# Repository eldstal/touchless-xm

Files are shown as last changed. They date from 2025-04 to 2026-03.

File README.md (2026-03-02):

# Touchlæss XM

A mod for Sony WH-1000XM2 (experimental), WH-1000XM3, WH-1000XM4 and WH-1000XM5 (experimental) headphones to remove the gesture-based touch controls and add physical buttons.

- [Project Status](#Status)
- [Compatible headsets](#compatibility)
- [Modifications](#modifications-and-faq)
- [How to program your board](#how-to-program)
- [Notes on ordering PCBs](#fabrication-notes)
- [License](#license)

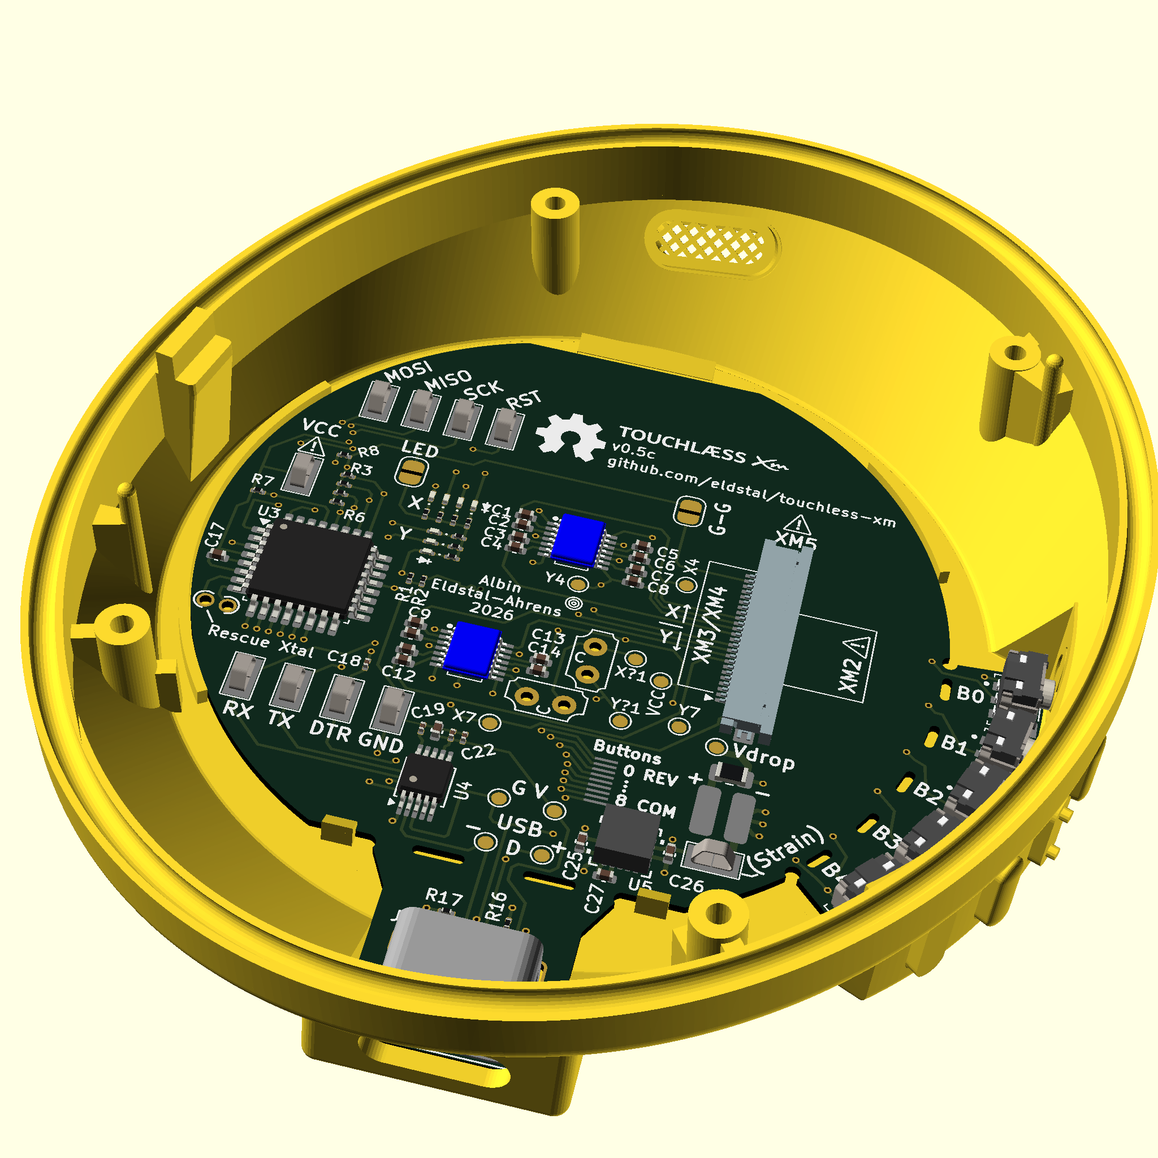
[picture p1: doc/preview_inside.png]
Inside view
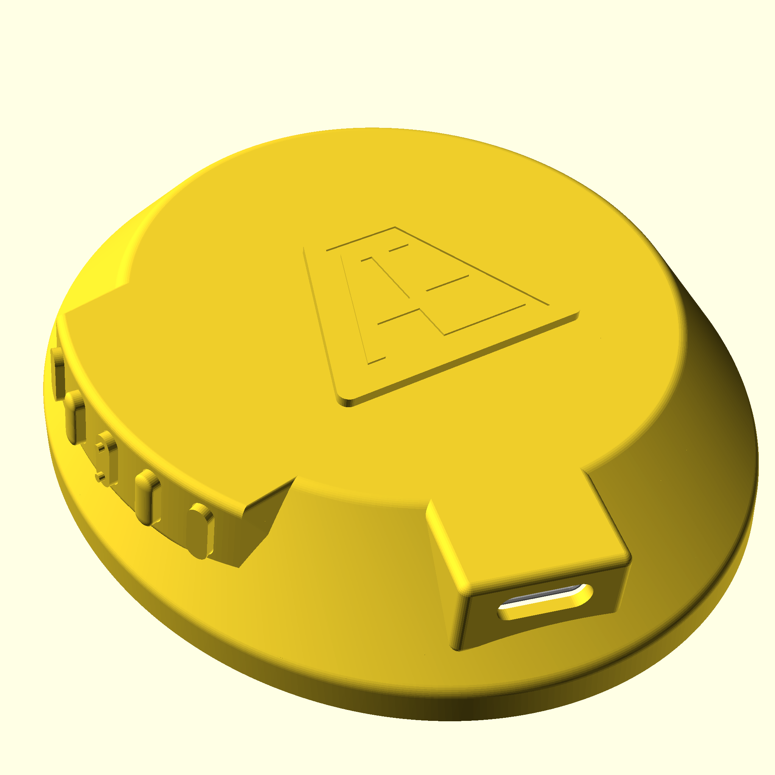
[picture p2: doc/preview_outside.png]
Outside view
 

## Status
The project is feature-complete and the electronics are functional. I'd call it a Beta product, since I'm the only user and still tweaking the design details.

### Case
The design has been 3D-printed and test fit against an XM4 headset. The mic grill looks good but prints awful.
Could be that we need to use a metal mesh inserted during the print.

The buttons have different top surfaces, so you can feel which is which. They've also been relocated to be less likely to be accidentally actuated.

STLs will be available both with and without USB ports, with and without the Æ logo.

### PCB
v0.5c of the board has been manufactured and works great!

I've installed it in my own headset for some day-to-day testing.

### Firmware
Ready to go. USB support (only for programming) is already included in the main board. The project uses platform.io and OptiBoot to run an Arduino-based firmware.

## Compatibility
I only have a pair of XM4 to test with, so the design is made to fit them. The connector is a 24-pin, but only XM5 has a cable that wide. For other models, insert your narrower cable carefully to match the lines on the PCB.

### 🟡 Sony WH-1000XM2 (Experimental)
I've laid out the board for experimental support for the XM2. These are the most different out of the bunch, so there are caveats.

⚠️**WARNING**⚠️
The OEM cable will not work, because the XM2 has the touch board's connector at the front. You will need a slightly longer cable **with opposite side contacts**. Possibly [This Würth 687712100002](https://eu.mouser.com/ProductDetail/Wurth-Elektronik/687712100002?qs=PhR8RmCirEbjmYLiy2w9eg%3D%3D) is suitable, but too long of a cable will cause interference. If you can trim it to length, that will improve the chances of success.

There is no bespoke connector for the XM2, you need to very carefully position it in the larger connector using the lines on the PCB.

It's also necessary to modify the firmware pin map slightly, since the Y pins are in the opposite order. Use `--environment xm2` when you compile the firmware.

If you've got a pair of XM2s and want to help me tune the compatibility, let me know!

### 🟡 Sony WH-1000XM3 (Probably compatible)
The XM3 touch board and battery connector appear to be electrically identical to XM4, so the PCB should be compatible. A different case design may be needed.

Insert your cable all the way at the top of the connector (there will be two unused pins at the bottom). Follow the lines in the silkscreen for guidance.

### 🟢 Sony WH-1000XM4 (Compatible)
The project is designed for these, so these will be the ones primarily tested. The OEM touch board has a flat cable which Touchlæss is designed to reuse.

Insert your cable all the way at the top of the connector (there will be two unused pins at the bottom). Follow the lines in the silkscreen for guidance.

The battery uses a 2-pin JST ZH series connector. There is no vertical space inside the case for a matching connector on the board, so I've resorted to soldering a Y-connector onto the Touchlæss pcb. Separate from the PCB BOM, you'll need one male and one female JST ZH-2 connector and some red/black cables.

### 🟡 Sony WH-1000XM5 (Possibly compatible)
Experimental support is included in the initial board design, but I **do not** own a pair of XM5 and cannot test them. The XM5 pinout is entirely based on reverse-engineering of photos, so I may have made a mistake! The Touchless board shouldn't be able to do any damage to the headphones. If you have a pair of XM5s and would like to help me test the compatibility, feel free to reach out!

At a minimum, the XM5 OEM design doesn't include a loose cable for us to reuse. You will need a suitable flat cable, which is 24-pin FFC with 0.5mm pitch and same-side connectors. [This Würth 687624050002](https://eu.mouser.com/ProductDetail/Wurth-Elektronik/687624050002?qs=P%2FTEqz%252BQfndQFFKLalvVUA%3D%3D) should work, but may not be the proper length.

The battery connector for XM5 is also different, a 3-pin of unknown design. If you have more information about this, let me know!

### 🟡 Sony WH-1000XM6 (Not even released yet)
With any luck, the XM6 touch board will be similar to the XM5. It will be a while before I get my hands on a new high-end headset to test it, though.

If you're getting a pair of XM6 and would like to send me some nice photos of the internals, I'll be very grateful!

### 🔴 Other manufacturers/headsets
**Highly** unlikely. At the very least, you'll need to figure out the pinout for the touch sensor board. Most likely there will be other things that need tuning as well. If you want to make something like touchless for a different headset, take a look at the [technical documentation](doc/README.md) for some pointers on how Touchless works.

## Modifications and FAQ

#### Will it drain my battery?
Not really. When idle, the board draws about 0.02 mA. When you're actively pressing/holding buttons it peaks at just under 13mA. This is on the order of one LED, and only when you're actively pushing buttons.

The DC converter on the board will stop working once the battery drops below about 0.7V, which is quite a bit before the headphones actually stop working. That means the buttons won't work when your battery is very low.

#### I don't want another USB port on my headset
That's OK, it's only needed for development (reprogramming the Touchless board without disassembling the headphones). Simply snap the USB connector off from the main board (see perforations) and print yourself a case without a USB block. Set `cap_type=nousb` in `xm4-cap.scad` to get a case that's closed at the bottom.

#### I don't like how you've placed the buttons
That's no problem! Snap the button portion off of the main board (see perforations) and use the solder points on the front or back to connect your own buttons placed wherever you want them. If you're keen on PCB design, it's not that hard to redesign the PCB for button placement (or add/remove buttons as needed).

There is no need for external resistors etc, just connect a switch between one button contact and the COM and you're good to go.

#### I don't have a 3D printer
No problem! If you remove the buttons and the USB addition (see above), the touchless board should fit inside the OEM ear cup (you have to remove the original touch board first, which may be destructive). Make cuts in the case as needed to mount buttons where you want them, and wire them up to the exposed button solder points on the front or back of the PCB.

#### The case is fine, but I want to reconfigure the buttons
Easiest way to do this is in the firmware. Take a look at [buttonmap.cpp](firmware/tobo/src/buttonmap.cpp) to switch and swap however you like. You'll need the included USB port or a serial cable to program the board after you've made your modifications. Instructions are [down below](#step-2-firmware).

#### Any tips for software modifications?
The board itself works as its own development board, of sorts. If you're going to be flashing new software via USB while testing, I recommend connecting the USB V (+5v) pad to the VCC test point as shown in [this photo](doc/usbpower.png). If you also short out the "LED" solder bridge you get LED indications of which touch points are currently being "touched".

**Please disconnect the USB power jumper before installing in the headset and connecting a battery**

#### I want to design my own case
Great! You can find the dimensions of the PCB [here](doc/tobo-measurements.svg). It's all  relative to the center of the circular area, so if your CAD program supports polar coordinates you'll have an easier time of it. You may also have use for `make vrml` in the pcb directory, which creates a VRML 3D export of the PCB to use as a reference in your model.

#### I want buttons for other features
That won't be possible, sorry. Touchlæss only works by simulating touches and swipes, so it can only do what the headphones allow you to do with the touch panel.

#### The buttons are too slow!
Yes. There is a significant delay between pushing a button and the headset responding. This isn't something we can control, since Touchlæss simulates touch gestures. If a swipe takes 120ms to perform, the headset can't react sooner than that.

#### I want the buttons on the left cup
That will be an adventure. Touchlæss interfaces with the board in the right cup, so you'll need to run wires across the headband to get to the other side. Not impossible, but certainly a lot of work.

#### I want to make and sell these
That's great! I won't ask for any royalties or whatever. If you do set something up, I'm happy to include a link here so people can buy from you.

## How to program

**Note:** The VCC loop on the PCB is powered by the headset battery via a step up/step down converter configured for 3.3V. **Do not** connect an external supply to this hook while the battery is connected. The loop is only needed in order to program and test the board without a headset connected.

The board will not take power from the USB connector by default. If you want to power it via USB while programming, connect a jumper between the USB V test point and the VCC test point as illustrated [here](doc/usbpower.png). Disconnect that jumper again before connecting a battery, please.

### Step 1: Bootloader
**This only needs to be done once per board**

When you have a fresh board with a factory-stock microcontroller, you'll have to start with the bootloader. For this step you need a hardware AVR programmer, for example:

- AVRISPmk2 (tested, works)
- An Arduino ([Instructions](https://docs.arduino.cc/built-in-examples/arduino-isp/ArduinoISP/#how-to-wire-your-boards))
- A [Bus Pirate](http://www.dangerousprototypes.com/docs/Bus_Pirate_AVR_Programming)
- An [USBAsp](https://www.fischl.de/usbasp/)

...or anything else supported by avrdude or [platform.io](https://platformio.org/). Install [the platform.io tools](https://platformio.org/install/cli) and let's go!

1. Connect your programmer to MISO, MOSI, SCK, GND and RST.
2. Connect the battery or the VCC terminal

| tobo | AVRISP 10-pin |Glasgow | BP harness |
|---|---|---|---|
| MOSI | 1 | PURP | 8 Pink |
| VCC  | 2 | ORG | 2 White |
| RST  | 5 | YEL | 6 Green |
| SCK  | 7 | PINK | 7 Yellow |
| MISO | 9 | BRN | 10 Brown |
| GND  | 10 | B/W | 1 Black |

If you're using a new kind of programmer, add the needed environment to `firmware/tobo/platformio.ini` to use your programmer.

**Warning** Ensure that your new environment extends `env:tobo`, so that the frequency and fuses are programmed properly. If you do not, you may need to temporarily connect an external crystal (see PCB markings) in order to recover the board.

```
cd firmware/tobo
pio run --environment avrispv2 --target bootloader
```

If there are no errors, congratulations! Your tobo board is an Arduino! You're ready for the next step.

### Step 2: Firmware
**If you've made changes to the code and want to update your board, this step is the only one you need to repeat**

If your board has the bootloader installed, you can put your ISP programmer away and use either the on-board USB port or your own serial adapter. This can be an FTDI cable, a different USB-to-serial adapter, or an arduino board with no microcontroller.

Hook up your serial cable to the tobo:

| tobo | serial adapter |
|---|---|
| RX | TX |
| TX | RX |
| GND | GND |
| DTR | DTR (if your cable has it) |
| RST | RST (if using an arduino) |
| VCC  | VCC **Only if you don't have the battery plugged in**|

```
cd firmware/tobo
pio run --target upload
```

If all went well, you're ready to go!

## Fabrication Notes
I've had the board produced by PCBWay with no issues. The following facts are useful while setting up an order:

- Order a 0.6mm PCB, to maximize the clearance inside the cap
- The smallest drilled hole is just over 0.2mm
- The XM4/XM5 connector footprints have narrow spacing between pads. This is a problem for the "Matte black" solder mask, but apparently possible with green/blue/red solder mask. If you want a matte black board, you have to allow for gaps in the solder mask at these connectors, and that may lead to shorts. Go with green or blue or red.

## Cost
The total cost for production, components and assembly of 5 boards was about $280 including shipping to Europe and VAT. That works out to about $56 per board.
You can reduce the BOM cost some by removing the USB port, USB-Serial circuitry and the LEDs. You could also save a bit by not populating the test loops, but it will make it more difficult to program the board.

## License
Touchlæss XM © 2026 by Albin Eldstål-Ahrens is licensed under Creative Commons BY-SA 4.0 

This means you are free to use, modify, distribute, remix, redesign the project however you wish as long as you
1. Credit the original work where relevant
2. Release your own modified work under a similar CC license

If you want to make and sell kits of this, feel free! If you make money from my work, please consider making a donation to a charitable organization as a thank you!

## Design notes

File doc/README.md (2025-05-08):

# Technical docs

## How does it work?

All three XM* headsets use the same basic principle for their touch controls, a grid of pads arranged in rows (Y) and columns (X). A pair of one X and one Y pad make up a single cell of a [mutual capacitive touch](https://www.elektormagazine.com/articles/how-do-capacitive-touch-sensors-work) matrix.

The controller board in the headphones uses various analog tricks to measure the capacitance of each X/Y pair, one at a time. When a finger is near, the capacitance between the pads **drops**.

### How does Touchless simulate this?

The easy and "safe" way to replace the touch board is to simulate the drop in capacitance, rather than trying to emulate the resulting analog signal. Touchless does this by connecting two capacitors between an X pad and a Y pad, and having one of the two capacitors connected via a multiplexer. This allows us to cut the capacitance in half by breaking the circuit, simulating a touch event.

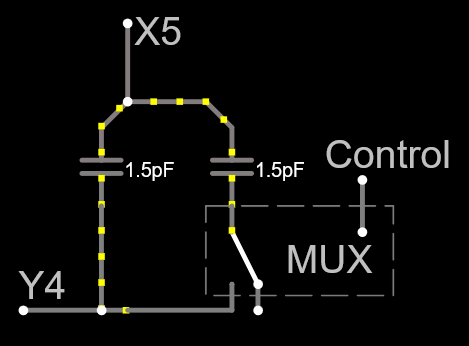
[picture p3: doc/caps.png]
Two capacitors, one controlled by a Mux


To support swiping motions, Touchless attaches to four horizontal and four vertical points in the touch matrix. This lets us control touch events at the following coordinates: 

```
-     -     -     -     -     -
-     -     -     -     -     -
-     -   (2,7)   -     -     -
-     -   (2,6)   -     -     -
-     -   (2,5)   -     -     -
-   (1,4) (2,4) (3,4) (4,4)   -
-     -     -     -     -     - 
-     -     -     -     -     -
```

Prototype testing indicates that three points are enough for a working swipe on the XM4, so this should be sufficient for all gestures.

## Original hardware
### WH1000-XM2

#### Battery connector
Battery appears to be a cellphone-type with no cables attached to it. It sits in a cradle which *does* have a cable+connector to the board, though.

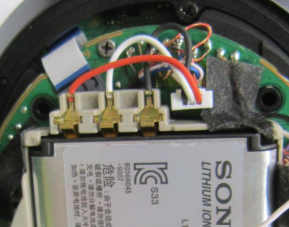
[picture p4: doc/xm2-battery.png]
XM2 battery from FCC filing


It's a 3-pin, likely JST but does not match the XM4 or XM5.

#### Touch board connector
FCC filing contains an OK shot of the touch board. The connector is at the front!

Pin 12 toward the top of the PCB/cap

| Pin  | Name |
|---|---|
|  12  |  ? |
|  11  |  X4  |
|  10  |  X3  |
| 9  |  X2  |
| 8  |  X1  |
| 7  |  X0  |
| 6  |  NC  |
| 5  |  Y3  |
| 4  |  Y2  |
| 3  |  Y1  |
| 2  |  Y0  |
| 1  |  ? |

Because the headphones have their connector at the front and tobo has its connector at the rear, you'll need a cable with **opposite side** connectors (i.e. exposed connectors on the front on one end and on the back on the other end). The cable also needs to be a bit longer than the OEM one.

### WH1000-XM3

Connectors (based on photos) appear to be identical to WH1000-XM4.

### WH1000-XM4

#### Battery connector
This is a 2-pin [JST ZH-series connector](https://www.jst-mfg.com/product/pdf/eng/eZH.pdf). The matching board connector is too tall to fit on the Touchless board, so the current design has no connector. Solder bare wires to the pcb and run them through a test loop for strain relief.

#### Touch board connector

FFC-22 with a 0.5mm pitch. With pin 22 at the top of the touch board, this is the pinout:

| Pin  | Name |
|---|---|
|  22  |  Some sort of ground loop around the edge |
|  21  |  GND |
|  20  |  NC  |
|  19  |  Unknown  |
|  18  |  X6  |
|  17  |  X5  |
|  16  |  X7  |
|  15  |  X8  |
|  14  |  X4  |
|  13  |  X3  |
|  12  |  X2  |
|  11  |  X1  |
|  10  |  X0  |
|  9 |  Y4  |
|  8 |  Y5  |
|  7 |  Y6  |
|  6 |  Y7  |
|  5 |  Y8  |
|  4 |  Y3  |
|  3 |  Y0  |
|  2 |  Y1  |
|  1 |  Y2  |

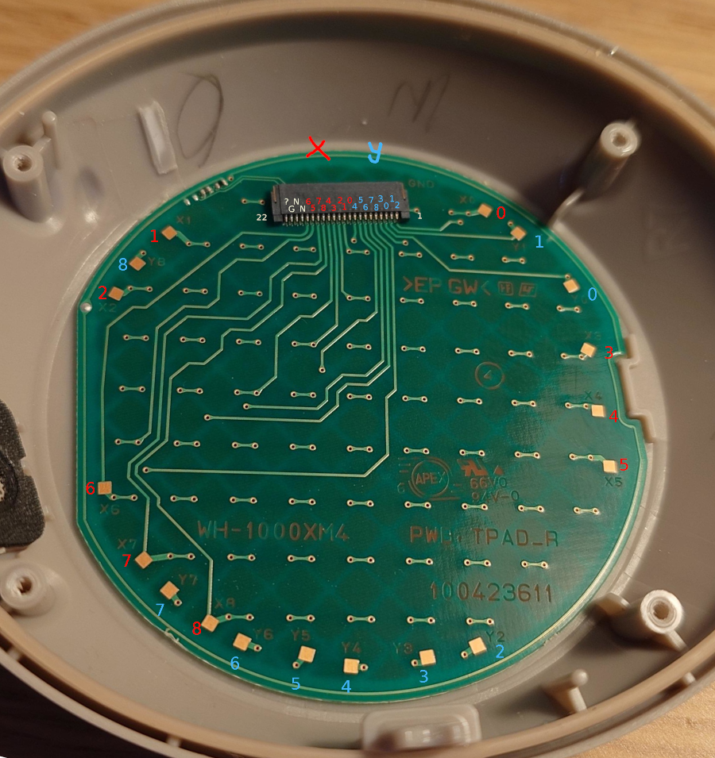
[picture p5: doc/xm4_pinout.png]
XM4 touch board with annotations


A compatible-ish part with a low profile is [Molex 545482272](https://www.molex.com/en-us/products/part-detail-pdf/545482272?display=pdf)

### WH1000-XM5

**This info is based on photos found online** and not from actual measurements on the real headset. Don't trust these numbers.

#### Battery connector
3-pin of unknown model. For sure not compatible with the XM4.

Inserted part seems to be ~7.3mm wide and inserted to 4mm depth.
The outer terminals are about 4mm apart, and there's a single smaller pin for the temp sensor.

It's labeled JST, and the closest I've been able to find is the [LBT-A](https://www.jst.com/products/crimp-style-connectors-wire-to-board-type/lbt-connector-a-type/), probably model `LBTAR-03V-2K-K(HF)`

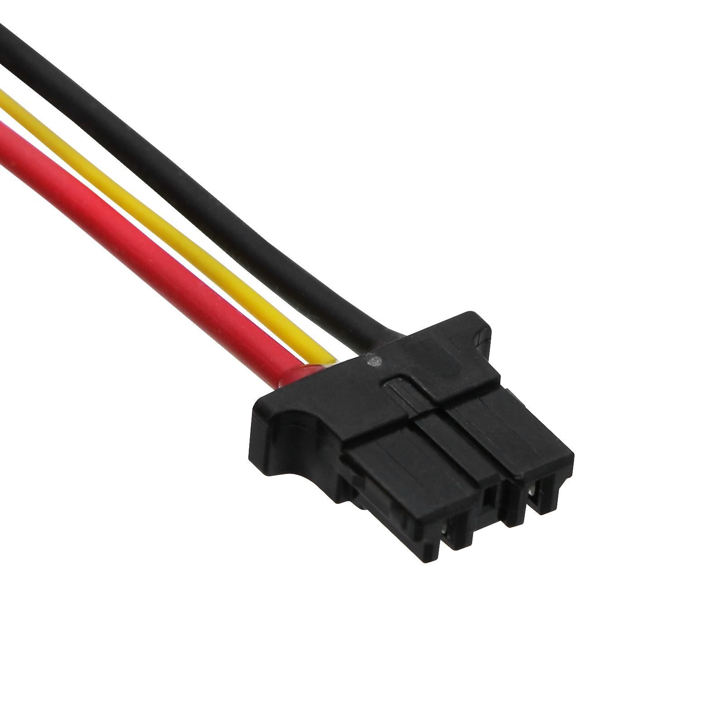
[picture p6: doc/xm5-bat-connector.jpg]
XM5 battery connector closeup


#### Touch board connector
24-pin 0.5mm pitch FPC integrated in the touch board (no connector on that end).

Touch panel is an FPC and has no connector of its own, the cable is combined with the circuit board itself. This pinout is for an imaginary connector, if you were to replace the FPC with a PCB and use a straight 24-pin FFC cable from the motherboard to the touch panel.

A suitable connector might be [Molex 545482472](https://www.molex.com/en-us/products/part-detail-pdf/545482472?display=pdf).

Pin 24 is at the top, 1 is at the bottom.

| Pin  | Name |
|---|---|
|  24  | Some kind of ground loop around the board  |
|  23  | GND  |
|  22  | NC |
|  21  | X0 |
|  20  | X6 |
|  19  | X5 |
|  18  | X7 |
|  17  | X8 |
|  16  | X4 |
|  15  | X3 |
|  14  | X2?  |
|  13  | X1?  |
|  12  | NC |
|  11  | Y4 |
|  10  | Y5 |
|  9 | Y6 |
|  8 | Y7 |
|  7 | Y8 |
|  6 | Y3 |
|  5 | Y9 |
|  4 | Y10  |
|  3 | Y2 |
|  2 | Y1 |
|  1 | Y0 |

The current PCB design for Touchless has an XM5 connector, which is based on this presumed pinout. If you have an XM5 headset and can provide a pinout, please let me know!

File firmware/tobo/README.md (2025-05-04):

# Touchless Board (tobo) firmware

## First time installation (bootloader)
Connect an ISP programmer (e.g. an AVRISPmk2 or an arduino wired up to MOSI/MISO/SCK/RST) and run

```
pio run --env avrispv2 --target bootloader --upload-port=/dev/ttyUSB0
```

## Update firmware
Connect to the RX/TX/RST hooks (or via the on-board USB connector) and run
```
pio run --target upload --upload-port=/dev/ttyUSB0
```

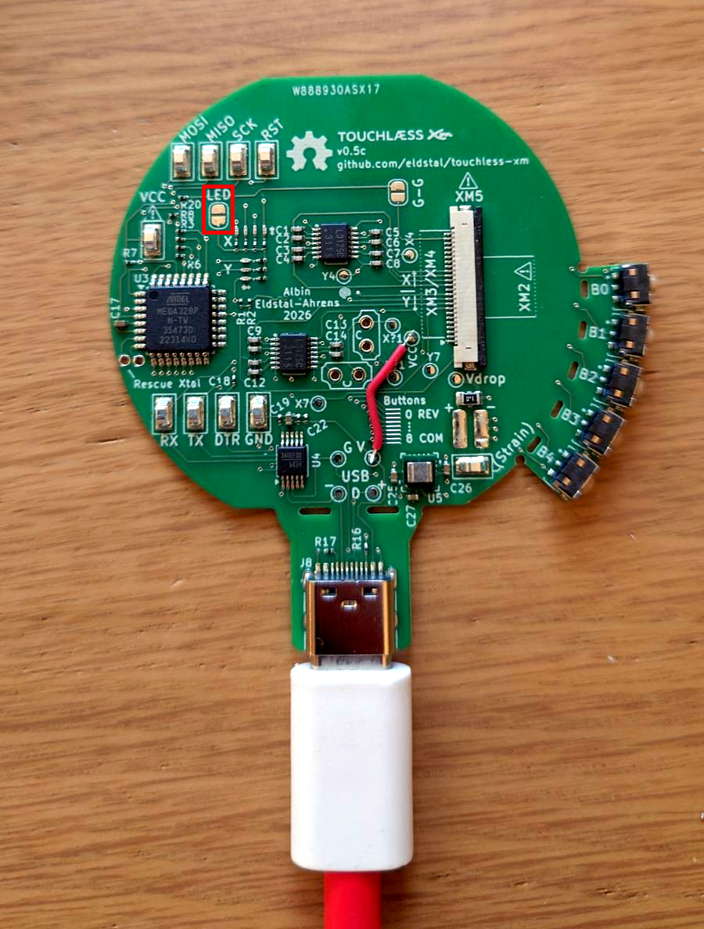
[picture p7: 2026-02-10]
doc/usbpower.png

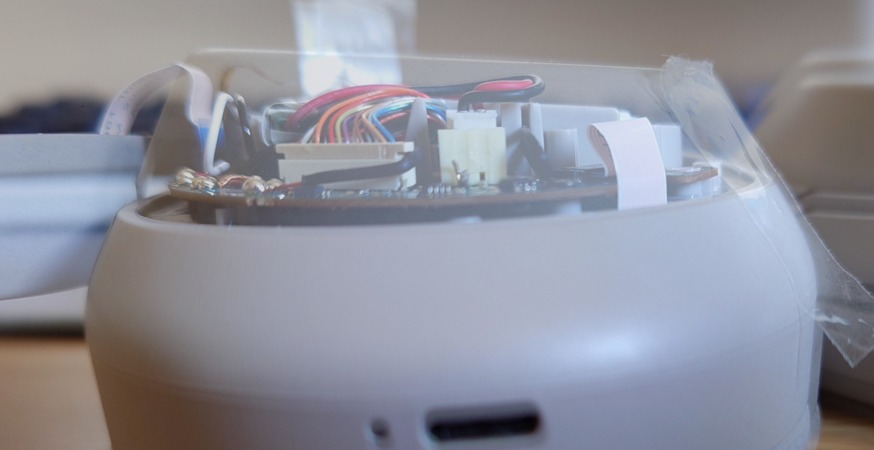
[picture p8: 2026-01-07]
doc/xm4-ghost.png

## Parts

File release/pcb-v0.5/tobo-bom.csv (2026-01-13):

Designator | Quantity per PCB | Manufacturer_Part_Number | Value | Mouser Part Number | LCSC Part Number | Datasheet | Footprint
C1-C14 | 14 | CC0402BRNPO9BN1R5 | 1.5pF |  | C282238 | ~ | Capacitor_SMD:C_0402_1005Metric
C17,C20,C25 | 3 | CL05A106MP5NUNC | 10uF |  | C315248 | ~ | Capacitor_SMD:C_0402_1005Metric
C18,C19,C21,C22 | 4 | TMK063ABJ104KP-F | 0.1uF | 963-TMK063ABJ104KP-F |  | ~ | Capacitor_SMD:C_0201_0603Metric
C26 | 1 | CL05A226MQ5QUNC | 22uF |  | C105226 | ~ | Capacitor_SMD:C_0402_1005Metric
C27 | 1 | CL05A225KO5NQNC | 2.2uF |  | C170151 | ~ | Capacitor_SMD:C_0402_1005Metric
D1-D7 | 7 | XL-0201UYC | LED |  | C5440628 | ~ | LED_SMD:LED_0201_0603Metric
J4 | 1 | 538-54548-2472 | 54548-2472 | 538-54548-2472 |  | https://www.molex.com/en-us/products/part-detail-pdf/545482472?display=pdf | tobo-footprints:molex-545482472
J8 | 1 | TYPE-C-31-M-12 | Hroparts Elec TYPE-C-31-M-12 |  | C165948 | https://www.usb.org/sites/default/files/documents/usb_type-c.zip | Connector_USB:USB_C_Receptacle_HRO_TYPE-C-31-M-12
R1-R8,R20 | 9 | ERJ-1GJJ102C | 1K | 667-ERJ-1GJJ102C |  | ~ | Resistor_SMD:R_0201_0603Metric
R9-R15 | 7 | ERJ-1GNF2700C | 270 | 667-ERJ-1GNF2700C |  | ~ | Resistor_SMD:R_0201_0603Metric
R16,R17 | 2 | ERA-1AEC512C | 5.1K | 667-ERA-1AEC512C |  | ~ | Resistor_SMD:R_0201_0603Metric
R27 | 1 | ERJ-6DQF1R0V | 1 | 667-ERJ-6DQF1R0V |  | ~ | Resistor_SMD:R_0805_2012Metric
S1-S5 | 5 | SKRTLBE010 | SKRTLBE010 | 688-SKRTLB |  | https://tech.alpsalpine.com/e/products/detail/SKRTLBE010/ | tobo-footprints:SKRTLBE010
U1,U2 | 2 | TC7MBL3125CFK(EL) | ~ | 757-TC7MBL3125CFKEL |  |  | tobo-footprints:VSSOP50P400X100-14N
U3 | 1 | ATmega328P-AN | ATmega328P-AN | 556-ATMEGA328P-AN | C618732 | http://ww1.microchip.com/downloads/en/DeviceDoc/ATmega328_P%20AVR%20MCU%20with%20picoPower%20Technology%20Data%20Sheet%2040001984A.pdf | Package_QFP:TQFP-32_7x7mm_P0.8mm
U4 | 1 | CH340E | CH340E |  | C99652 | https://www.mpja.com/download/35227cpdata.pdf | tobo-footprints:MSOP-10_3x3mm_P0.5mm_narrowpads
U5 | 1 | MAXM20343AMP+ | MAXM20343AMP+ | 700-MAXM20343AMP+ |  | MAXM20343AMP+ | tobo-footprints:21-100447_ADI
U6-U13,U15,U16 | 10 | 5015 | 5015 | 534-5015 |  | http://www.keyelco.com/product-pdf.cfm?p=1353 | tobo-footprints:5015

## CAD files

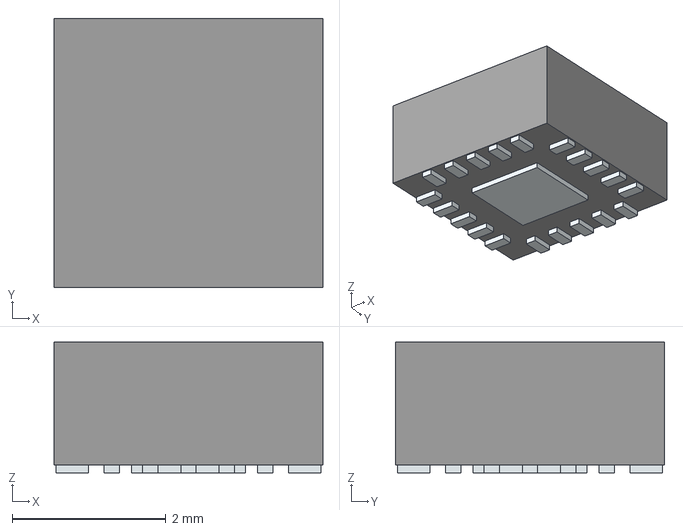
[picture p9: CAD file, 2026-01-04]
pcb/tobo/3dmodels/MAXM20343AMP+.stp
3.50 x 3.50 x 1.70 mm
Pins

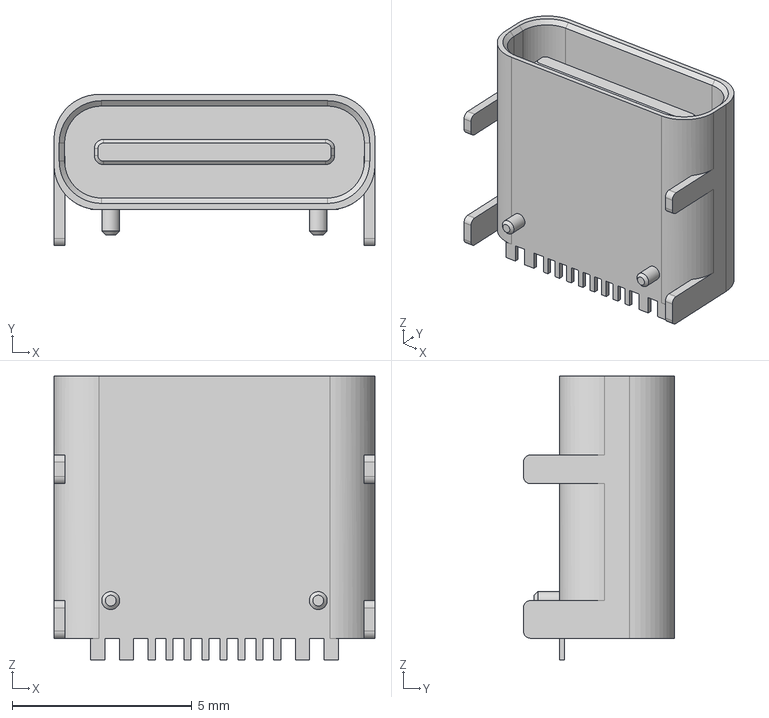
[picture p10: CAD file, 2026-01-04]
pcb/tobo/3dmodels/HRO TYPE-C-31-M-12.step
8.94 x 4.21 x 7.90 mm

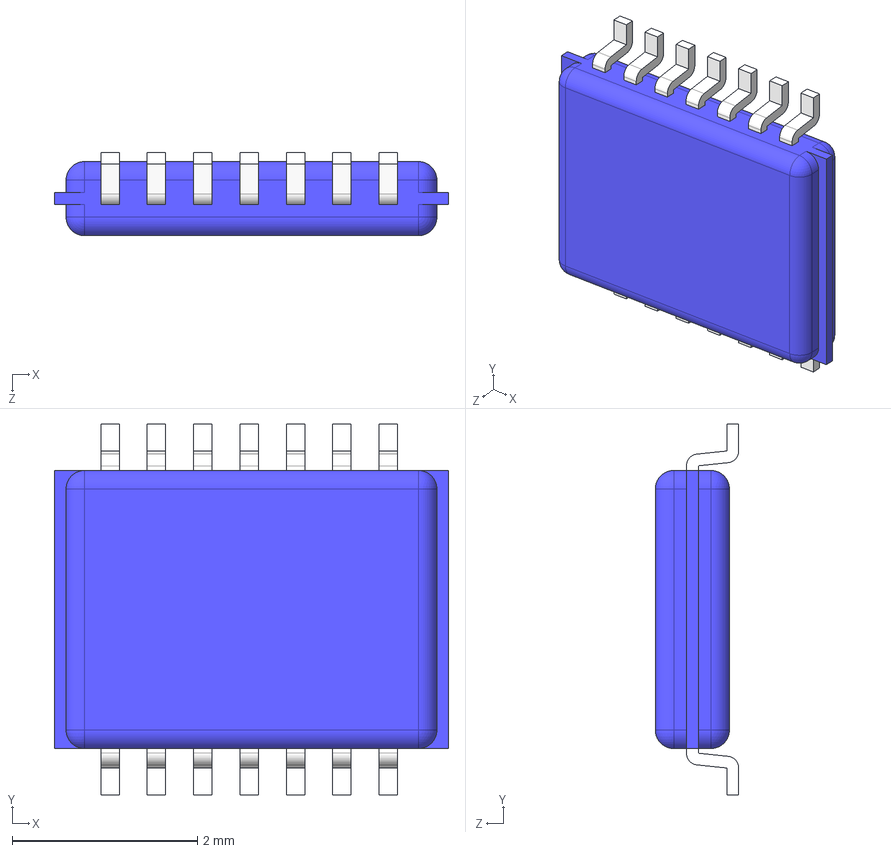
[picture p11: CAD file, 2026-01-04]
pcb/tobo/3dmodels/TC7MBL3125CFK_EL_.stp
4.25 x 4.00 x 0.9 mm

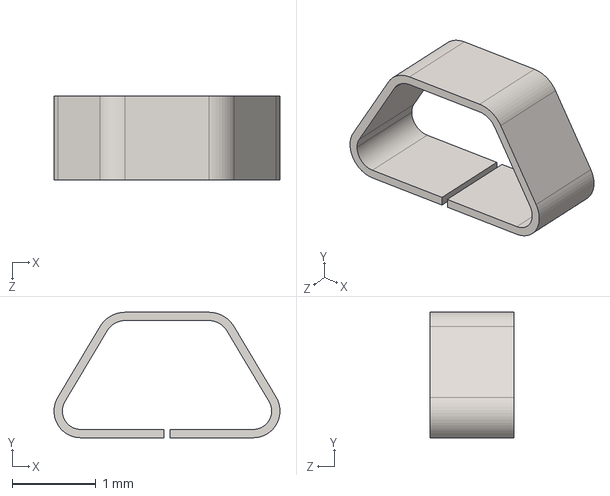
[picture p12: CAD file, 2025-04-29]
pcb/tobo/3dmodels/5015.stp
2.70 x 1.50 x 1.00 mm

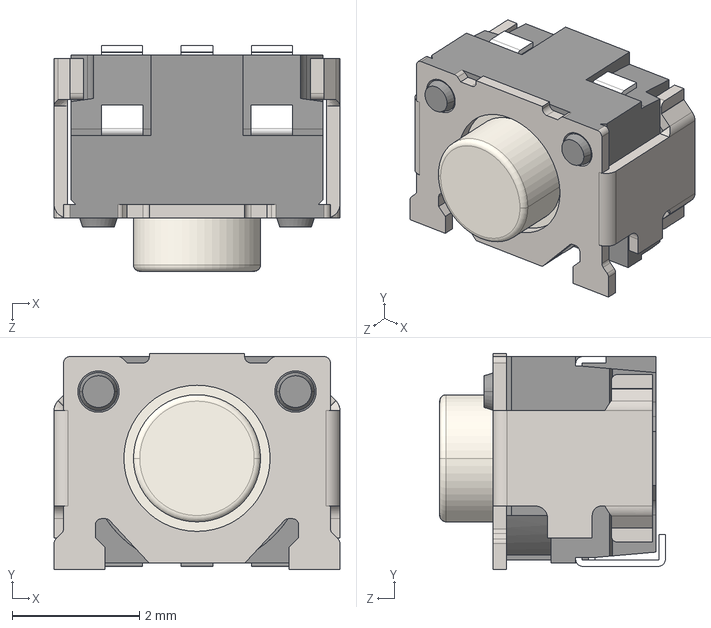
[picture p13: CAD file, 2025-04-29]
pcb/tobo/3dmodels/SKRTLBE010.stp
4.50 x 3.40 x 3.55 mm

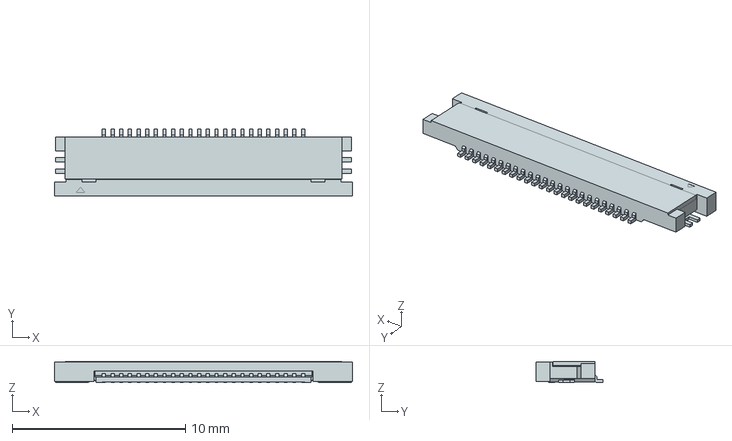
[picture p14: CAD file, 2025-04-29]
pcb/tobo/3dmodels/545482472.stp
17.2 x 3.85 x 1.23 mm

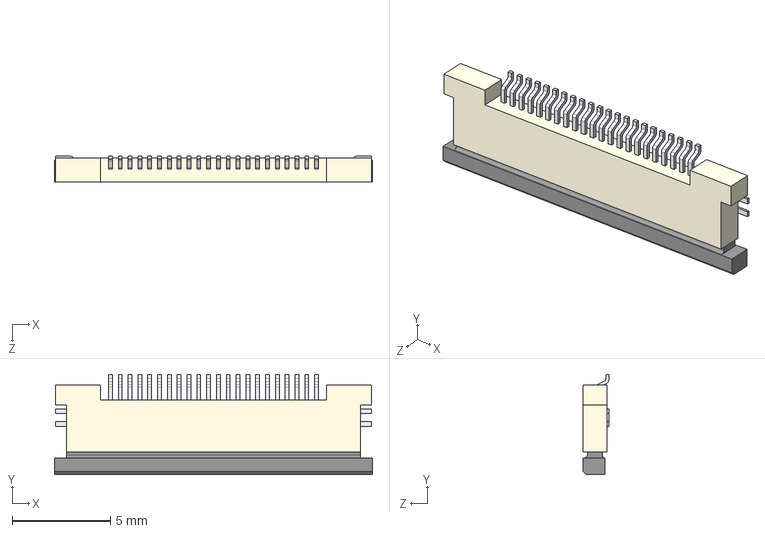
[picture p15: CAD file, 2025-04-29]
pcb/tobo/3dmodels/54548-2272.stp
16.2 x 5.10 x 1.30 mm

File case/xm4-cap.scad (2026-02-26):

//
// Right outside cup for WH1000-XM4
//

/* [Quality etc] */
$fa = 1;
$fs = 0.2;


include_print_supports = true;

/* [Parts included] */
// Render the main body
show_cap = true;

// Render PCB (run make in pcb/)
show_pcb = true;

// Render buttons
show_buttons = true;

// Render microphone grill
show_grill = true;

// Render the logo on the cap
show_logo = true;

/* [Body options] */
cap_type = "usb";        // [usb, nousb, oem]

// Partial rendering
cap_portion = "full";       // [full, mount, cutaway, clearance, buttons, button-cutaway, grill]

body_thickness = 1.4;

gasket_thickness=1.75;

// Width of the flat rim around the bottom
rim_width = 2.6;

/* [Logo options] */
logo_mounted = false;

// Include the mount for the logo amulet on the outside of the cap
with_logo = true;




/* [PCB options] */
// Replace the fancy render with a placeholder for test fits
pcb_type_dummy = false;
pcb_thickness = 0.6;
pcb_clearance = 0.1;
usb_board_h = 4.5;



/* [Button options] */
buttons_mounted = false;

// Distance from PCB center to switch contact surface
button_contact_r = 32.25;

// mm between the button and the button hole
button_side_clearance = 0.1;

// mm between the button and the body
button_depth_clearance=0.15;


/* [Mic grill options] */
grill_mounted = false;

// Oversize the mic grill to make it stick
mic_grill_friction_fit = 0.05;

// Mic hole frame protrusion to meet the mic
mic_grill_protrude_inside = 0.8;

mic_hole_height = 2.5;
mic_hole_width = 8;

/* [Hidden] */
outside_width = 69;
outside_height = 80;
outside_max_depth = 17.1;
top_circle_diameter = 57.5;
top_circle_angle_x = 1.9;
top_circle_angle_y = 5;
top_circle_off_x = 2;       // More like 1 for the OEM, but we needed more button space
top_circle_off_y = 1;
top_circle_off_z_c = 14.5;
inside_depth_c = top_circle_off_z_c - body_thickness;



// The centers of the round radii of the mic hole

mic_hole_x1 = 6.27;
mic_hole_y1 = 39.39;

mic_hole_x2 = 11.96;
mic_hole_y2 = 37.49;

//mic_hole_xc = (mic_hole_x1 + mic_hole_x2) / 2;
mic_hole_xc = 17.34 - 8.5;
mic_hole_yc = (mic_hole_y1 + mic_hole_y2) / 2;
mic_hole_zc = 8;

// Actual opening

// The hole in the case
mic_hole_cut_height = 4;

// Actual opening
mic_hole_cc = mic_hole_width - mic_hole_height;


// Set mic_hole_feeler and tweak until the red panel just breaks the outside edge of the casing
mic_hole_feeler = false;
mic_hole_angle_x = 31.8;
mic_hole_angle_z = 1;
mic_hole_angle_y = -5;
mic_hole_distance = 36.4;
mic_grill_alignment = -1.2;
//mic_hole_angle_z = atan((mic_hole_y2 - mic_hole_y1) / (mic_hole_x2 - mic_hole_x1));


// Heading to the mic hole from the origin
mic_hole_dir_z = -atan((mic_hole_xc) / (mic_hole_yc));
mic_hole_dir_x = asin(mic_hole_zc / mic_hole_distance);


module bottom_outer_edge() {
    import("xm4-cap-outline-centered.svg", center=true);
}

module edge_with_rounding(radius=1.75) {
    
    difference() {
        minkowski() {
            resize([outside_width - 2*radius, outside_height - 2*radius, 0], true)
            linear_extrude(0.01, center=true)
                import("xm4-cap-outline-centered.svg", center=true);
            
            
            sphere(r=radius);
        }
        
        translate([0, 0, -radius])
        scale([outside_width*2, outside_height*2, radius*2])
        cube(center=true);
    }
}


module bottom_gasket(thickness=gasket_thickness,
                     center_width=outside_width - (rim_width),
                     center_height=outside_height - rim_width) {

    // Give the cutout it a little bit of a lip, to maybe hold on to the rubber gasket
    translate([0, 0, thickness/5])
    minkowski() {
        // A thin, flat sliver of the proper shape
        difference() {
            
            linear_extrude(0.01, center=true)
            resize([center_width+0.01, center_height+0.01, 0], true)
                bottom_outer_edge();
                
            
            linear_extrude(0.1, center=true)
            resize([center_width-0.01, center_height-0.01, 0], true)
                bottom_outer_edge();
        }
        
        sphere(d=thickness);
        
    }
}

// Position an element relative to the center of the PCB board's floor,
// i.e. center of the inside of the top circular cap
module inside_top_center() {
        translate([top_circle_off_x, top_circle_off_y, inside_depth_c])
        rotate([top_circle_angle_x, top_circle_angle_y, 0])
        children();
}

// Position an element relative to the center of the PCB itself
// on the inside of the cap. This is different from inside_top_center()
// because the PCB isn't at the exact center anymore.
module inside_pcb_center() {
    inside_top_center()
    // Offset the PCB so that the buttons don't become
    // the thing the headset rests on
    translate([1, 1, 0])
    rotate([0, 0, -15])
    children();
}

// Position an element relative to the center of the circular outside
// of the cap, i.e. the middle of the visible side.
module outside_top_center() {
    translate([top_circle_off_x, top_circle_off_y, 0])
    translate([0, 0, top_circle_off_z_c])
    rotate([top_circle_angle_x, top_circle_angle_y, 0])
    children();
}

module top_circle() {
    translate([top_circle_off_x, top_circle_off_y, 0])
    translate([0, 0, top_circle_off_z_c])
    rotate([top_circle_angle_x, top_circle_angle_y, 0])
        linear_extrude(0.001, center=false)
        circle(d = top_circle_diameter);
}

module top_circle_with_rounding(radius, off_z_c, cap_radius_modifier=0) {
    translate([top_circle_off_x, top_circle_off_y, 0])
    translate([0, 0, off_z_c])
    rotate([top_circle_angle_x, top_circle_angle_y, 0])
    translate([0, 0, -radius])
    rotate_extrude() {
        translate([top_circle_diameter/2 - radius + cap_radius_modifier, 0, 0])
        circle(radius);
    }
}

module case_shoulder(width=outside_width, height=outside_height, rounding=1.75) {
        // Slightly smaller, to prevent interference with hinge fork
        resize([width-0.2, height-0.2, 0], true)
        translate([0, 0, 3.1])
            edge_with_rounding();
}


module standard_cup_shape (width, height, depth_c=top_circle_off_z_c, rounding=1.75, cap_radius_modifier=0){

    
    hull() {
    
        case_shoulder(width, height, rounding);
    
        resize([width, height, 0], true)
        linear_extrude(0.01, center=false)
            bottom_outer_edge();
 
        
        top_circle_with_rounding(rounding, depth_c, cap_radius_modifier=cap_radius_modifier);
       
    }
}

module case_rim() {
    linear_extrude(7, center=false)
    difference() {
        bottom_outer_edge();
        
        resize([outside_width - 2*rim_width, outside_height - 2*rim_width, 0], true)
        bottom_outer_edge();
    }
    

}

module standard_case (cut=false) {
    
    if (!cut) {
        // The shell itself
        standard_cup_shape(outside_width, outside_height, top_circle_off_z_c);
        
    } else {
        // The inside cavity of the case
        
       
        // Naive approach. Scale the cup down in all directions to make
        // the cavity. This doesn't give a uniformly thick end cap,
        // so in slicing it may give a weird effect on the inside surface.
        translate([0, 0, -0.01])
        standard_cup_shape(outside_width-2*body_thickness, outside_height-2*body_thickness, inside_depth_c, rounding=0.5, cap_radius_modifier=-(body_thickness/3));
        
        // Route down the inside cap so it's perfectly flat (compared to the outside)
        inside_top_center() {
            translate([0, 0, -5])
            cylinder(5, top_circle_diameter/2-2, top_circle_diameter/2-1);
        }

    }
}


module screw_post(diameter, height, do_inner_support, inner_support_clearance, inner_support_length) {

        translate([0, 0, height/2])
        difference() {
                cylinder(h=height, r=diameter/2, center=true);
                cylinder(h=height*2, r=1.5/2, center=true);
        }
        
        // Outside support
        translate([0, diameter/2 - 0.2, 0.5])
        resize([1.2, diameter, height-1])
            translate([0, 0.5, 0.5])
            cube(1, center=true);
        
        if (do_inner_support) {
            // Inside support
            translate([0, -(diameter/2 - 0.2), inner_support_clearance])
            resize([1.2, inner_support_length + 0.2, height-inner_support_clearance])
                translate([0, -0.5, 0.5])
                cube(1, center=true);
        }
}
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

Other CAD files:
release/pcb-v0.5/tobo.scad

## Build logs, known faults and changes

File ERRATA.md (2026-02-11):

# ERRATA

## PCB v0.5c
This board revision works as-is!

## PCB v0.3a
The RX and TX lines are mislabeled on the serial programming interface,
and the connections to the CH340 are incorrect.

### Solution
If you're programming with a serial cable, just swap RX and TX (connect RX on your cable to RX on the board, and vice versa).

To get USB programming working, cut the connections above the RX/TX attachment loops and connect them to the vias just above with bodge wires.

To get more to solder to, you can carefully sand the soldermask down. I used 240 grit sand paper to good effect. Be very careful not to desolder or damage the capacitor nearby.

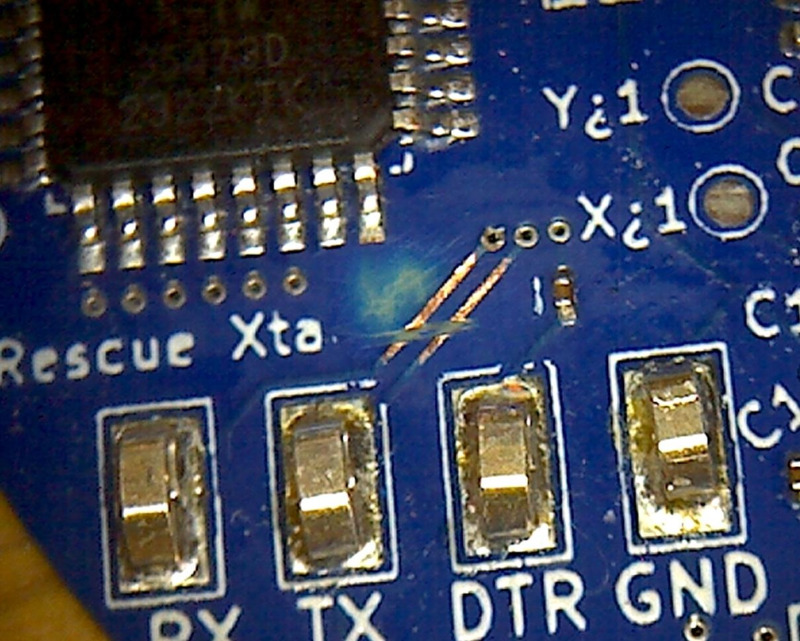
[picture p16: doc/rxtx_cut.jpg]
Sanding away the solder mask and cutting the two traces


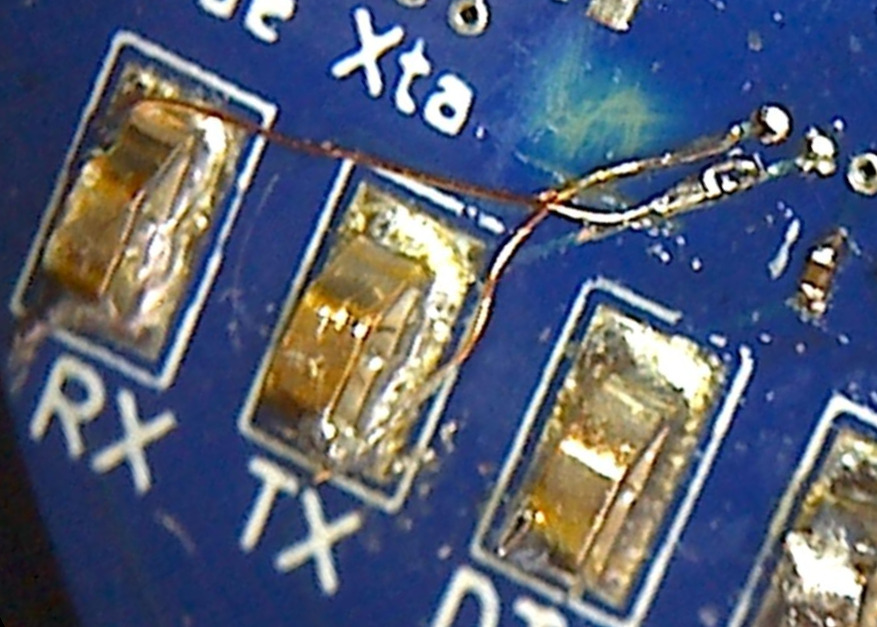
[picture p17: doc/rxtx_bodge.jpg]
Crossing the traces with a pair of very thin copper enamel wires


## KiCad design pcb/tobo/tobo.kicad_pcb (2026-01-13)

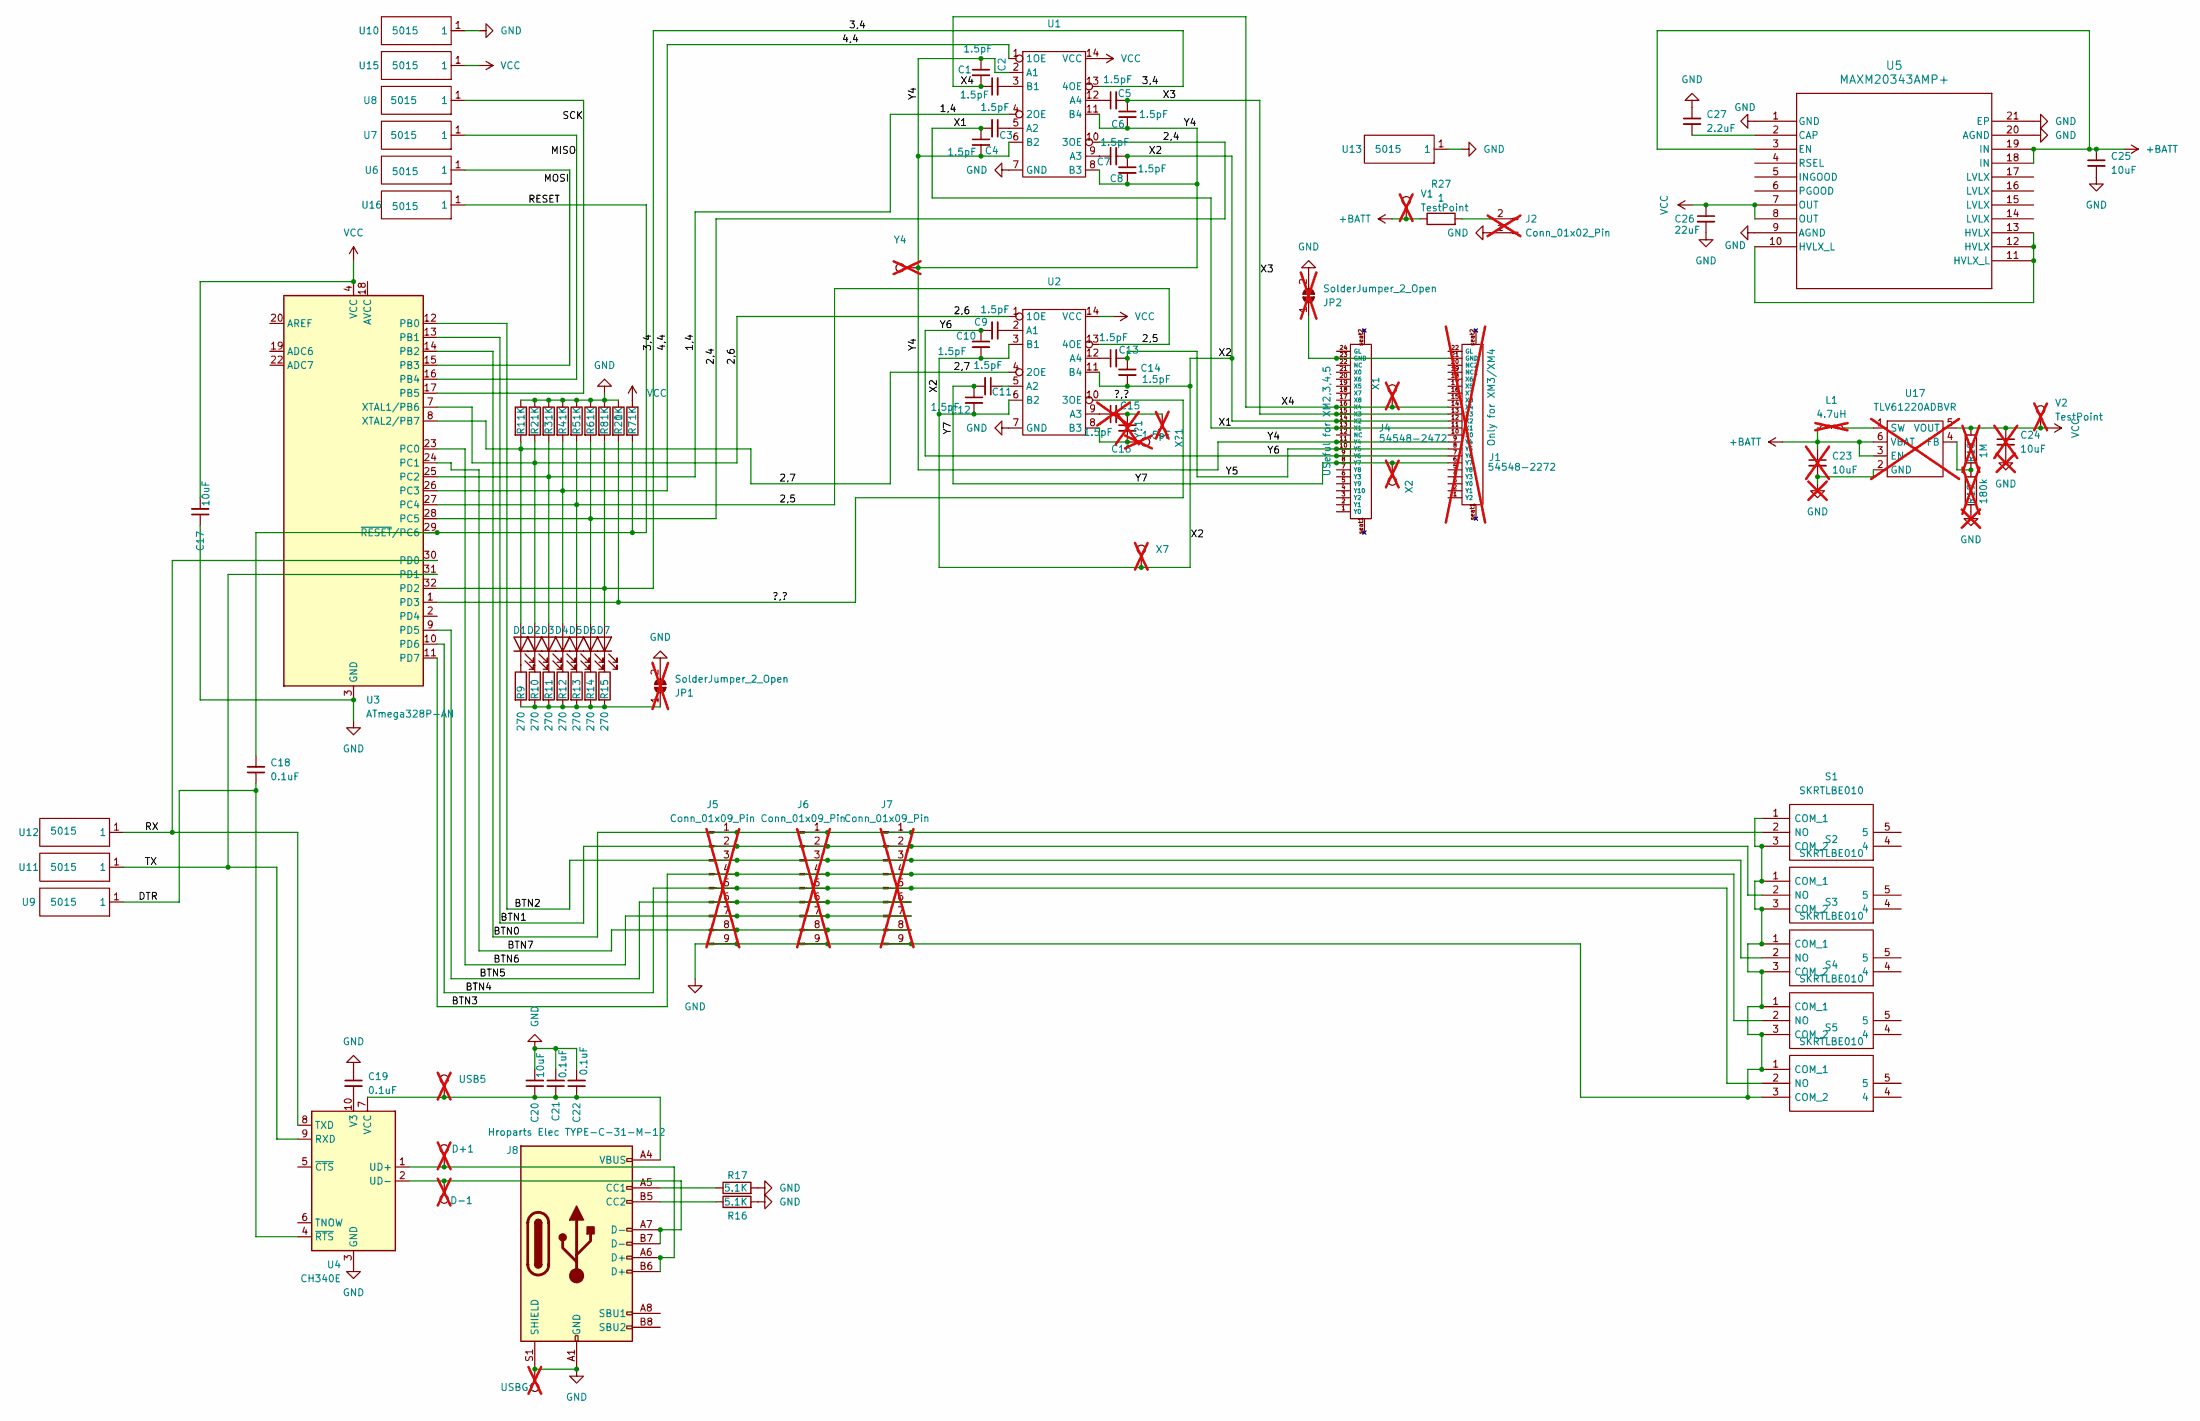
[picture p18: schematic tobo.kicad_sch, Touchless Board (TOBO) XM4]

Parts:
C1, C2, C3, C4, C5, C6, C7, C8, C9, C10, C11, C12, C13, C14: 1.5pF; C_0402_1005Metric; Manufacturer_Part_Number CC0402BRNPO9BN1R5; LCSC Part Number C282238
C15, C16: 1.5pF; C_Disc_D5.0mm_W2.5mm_P2.50mm; Manufacturer_Part_Number CC0402BRNPO9BN1R5; LCSC Part Number C282238; not fitted
C17, C20, C25: 10uF; C_0402_1005Metric; Manufacturer_Part_Number CL05A106MP5NUNC; LCSC Part Number C315248
C18, C19, C21, C22: 0.1uF; C_0201_0603Metric; Mouser Part Number 963-TMK063ABJ104KP-F
C23, C24: 10uF; C_0402_1005Metric; Manufacturer_Part_Number CL05A106MP5NUNC; LCSC Part Number C315248; not fitted
C26: 22uF; C_0402_1005Metric; Manufacturer_Part_Number CL05A226MQ5QUNC; LCSC Part Number C105226
C27: 2.2uF; C_0402_1005Metric; Manufacturer_Part_Number CL05A225KO5NQNC; LCSC Part Number C170151
D1, D2, D3, D4, D5, D6, D7: LED; LED_0201_0603Metric; Manufacturer_Part_Number XL-0201UYC; LCSC Part Number C5440628
D+1: TestPoint; TestPoint_Pad_D1.0mm; not fitted
D-1: TestPoint; TestPoint_Pad_D1.0mm; not fitted
J1: 54548-2272; molex-545482272; Mouser Part Number 538-54548-2272; not fitted
J2: Conn_01x02_Pin; power-cable; not fitted
J4: 54548-2472; molex-545482472; Mouser Part Number 538-54548-2472
J5: Conn_01x09_Pin; button_breakout_2.54mm; not fitted
J6, J7: Conn_01x09_Pin; button_breakout_0.5mm; not fitted
J8: Hroparts Elec TYPE-C-31-M-12; USB_C_Receptacle_HRO_TYPE-C-31-M-12; Manufacturer_Part_Number TYPE-C-31-M-12; LCSC Part Number C165948
JP1, JP2: SolderJumper_2_Open; SolderJumper-2_P1.3mm_Open_RoundedPad1.0x1.5mm; not fitted
L1: 4.7uH; L_1008_2520Metric; Mouser Part Number 571-365708M4R7T; not fitted
R1, R2, R3, R4, R5, R6, R7, R8, R20: 1K; R_0201_0603Metric; Mouser Part Number 667-ERJ-1GJJ102C
R9, R10, R11, R12, R13, R14, R15: 270; R_0201_0603Metric; Mouser Part Number 667-ERJ-1GNF2700C
R16, R17: 5.1K; R_0201_0603Metric; Mouser Part Number 667-ERA-1AEC512C
R18: 1M; R_0201_0603Metric; Mouser Part Number 667-ERJ-1GJF1004C; not fitted
R19: 180k; R_0201_0603Metric; Mouser Part Number 667-ERJ-1GJF1803C; not fitted
R27: 1; R_0805_2012Metric; Mouser Part Number 667-ERJ-6DQF1R0V
S1, S2, S3, S4, S5: SKRTLBE010; Mouser Part Number 688-SKRTLB
U1, U2: VSSOP50P400X100-14N; Mouser Part Number 757-TC7MBL3125CFKEL
U3: ATmega328P-AN; TQFP-32_7x7mm_P0.8mm; Mouser Part Number 556-ATMEGA328P-AN
U4: CH340E; MSOP-10_3x3mm_P0.5mm_narrowpads; Manufacturer_Part_Number CH340E; LCSC Part Number C99652
U5: MAXM20343AMP+; 21-100447_ADI; Manufacturer_Part_Number MAXM20343AMP+; Mouser Part Number 700-MAXM20343AMP+
U6, U7, U8, U9, U10, U11, U12, U13, U15, U16: 5015; Manufacturer_Part_Number 5015; Mouser Part Number 534-5015
U17: TLV61220ADBVR; SOT-23-6; Mouser Part Number 595-TLV61220ADBVR; not fitted
USB5: TestPoint; TestPoint_Pad_D1.0mm; not fitted
USBG1: TestPoint; TestPoint_Pad_D1.0mm; not fitted
V1, V2: TestPoint; TestPoint_Pad_D1.0mm; not fitted
X1, X2, X7: TestPoint; TestPoint_Pad_D1.0mm; not fitted
X?1: TestPoint; TestPoint_Pad_D1.0mm; not fitted
Y4: TestPoint; TestPoint_Pad_D1.0mm; not fitted
Y?1: TestPoint; TestPoint_Pad_D1.0mm; not fitted

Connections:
+BATT: C23.1, C25.1, L1.1, R27.1, U5.3 (EN), U5.18 (IN), U5.19 (IN), U17.3 (EN), U17.6 (VBAT), V1.1
/1,4: D3.2 (A), R3.2, U1.4 (2OE), U3.25 (PC2)
/2,4: D6.2 (A), R6.2, U1.10 (3OE), U3.28 (PC5)
/2,5: D5.2 (A), R5.2, U2.13 (4OE), U3.27 (PC4)
/2,6: D2.2 (A), R2.2, U2.1 (1OE), U3.7 (XTAL1/PB6)
/2,7: D1.2 (A), R1.2, U2.4 (2OE), U3.8 (XTAL2/PB7)
/3,4: D7.2 (A), R8.2, U1.13 (4OE), U3.32 (PD2)
/4,4: D4.2 (A), R4.2, U1.1 (1OE), U3.26 (PC3)
/?,?: R20.2, U2.10 (3OE), U3.1 (PD3)
/BTN0: J5.1, J6.1, J7.1, S1.2 (NO), U3.14 (PB2)
/BTN1: J5.2, J6.2, J7.2, S2.2 (NO), U3.13 (PB1)
/BTN2: J5.3, J6.3, J7.3, S3.2 (NO), U3.12 (PB0)
/BTN3: J5.4, J6.4, J7.4, S4.2 (NO), U3.11 (PD7)
/BTN4: J5.5, J6.5, J7.5, S5.2 (NO), U3.10 (PD6)
/BTN5: J5.6, J6.6, J7.6, U3.9 (PD5)
/BTN6: J5.7, J6.7, J7.7, U3.23 (PC0)
/BTN7: J5.8, J6.8, J7.8, U3.24 (PC1)
/DTR: C18.1, U4.4 (~RTS), U9.1
/MISO: U3.16 (PB4), U7.1
/MOSI: U3.15 (PB3), U6.1
/RESET: C18.2, R7.2, U3.29 (~RESET/PC6), U16.1
/RX: U3.30 (PD0), U4.8 (TXD), U12.1
/SCK: U3.17 (PB5), U8.1
/TX: U3.31 (PD1), U4.9 (RXD), U11.1
/X1: C3.2, C4.1, J1.11 (X1), J4.13 (X1)
/X2: C7.2, C8.1, C10.2, C12.2, C14.2, J1.12 (X2), J4.14 (X2), U2.3 (B1), U2.6 (B2), U2.11 (B4), X7.1
/X3: C5.2, C6.1, J1.13 (X3), J4.15 (X3)
/X4: C1.2, C2.1, J1.14 (X4), J4.16 (X4), X1.1
/Y4: C1.1, C4.2, C6.2, C8.2, J1.9 (Y4), J4.11 (Y4), U1.2 (A1), U1.6 (B2), U1.8 (B3), U1.11 (B4), Y4.1
/Y5: C13.2, C14.1, J1.8 (Y5), J4.10 (Y5)
/Y6: C9.2, C10.1, J1.7 (Y6), J4.9 (Y6)
/Y7: C11.2, C12.1, J1.6 (Y7), J4.8 (Y7), X2.1
GND: C17.1, C19.1, C20.2, C21.2, C22.2, C23.2, C24.2, C25.2, C26.2, C27.1, J2.1, J5.9, J6.9, J7.9, J8.A1 (GND), J8.A12 (GND), J8.B1 (GND), J8.B12 (GND), J8.S1 (SHIELD), JP1.2 (B), JP2.2 (B), R1.1, R2.1, R3.1, R4.1, R5.1, R6.1, R8.1, R16.2, R17.2, R19.2, R20.1, S1.1 (COM_1), S1.3 (COM_2), S2.1 (COM_1), S2.3 (COM_2), S3.1 (COM_1), S3.3 (COM_2), S4.1 (COM_1), S4.3 (COM_2), S5.1 (COM_1), S5.3 (COM_2), U1.7 (GND), U2.7 (GND), U3.3 (GND), U3.5 (GND), U3.21 (GND), U4.3 (GND), U5.1 (GND), U5.9 (AGND), U5.20 (AGND), U5.21 (EP), U10.1, U13.1, U17.2 (GND), USBG1.1
unnamed: C15.2, C16.1, X?1.1
unnamed: D1.1 (K), R9.1
unnamed: D2.1 (K), R10.1
unnamed: D3.1 (K), R11.1
unnamed: D4.1 (K), R12.1
unnamed: D5.1 (K), R13.1
unnamed: D6.1 (K), R14.1
unnamed: D7.1 (K), R15.1
unnamed: J2.2, R27.2
unnamed: J1.21 (GND), J4.23 (GND), JP2.1 (A)
unnamed: J8.A5 (CC1), R17.1
unnamed: J8.B5 (CC2), R16.1
unnamed: JP1.1 (A), R9.2, R10.2, R11.2, R12.2, R13.2, R14.2, R15.2
unnamed: L1.2, U17.1 (SW)
unnamed: R18.2, R19.1, U17.4 (FB)
unnamed: C3.1, U1.5 (A2)
unnamed: C7.1, U1.9 (A3)
unnamed: C5.1, U1.12 (A4)
unnamed: C2.2, U1.3 (B1)
unnamed: C9.1, U2.2 (A1)
unnamed: C11.1, U2.5 (A2)
unnamed: C15.1, U2.9 (A3)
unnamed: C13.1, U2.12 (A4)
unnamed: C16.2, U2.8 (B3), Y?1.1
unnamed: D+1.1, J8.A6 (D+), J8.B6 (D+), U4.1 (UD+)
unnamed: D-1.1, J8.A7 (D-), J8.B7 (D-), U4.2 (UD-)
unnamed: C19.2, U4.10 (V3)
unnamed: C20.1, C21.1, C22.1, J8.A4 (VBUS), J8.A9 (VBUS), J8.B4 (VBUS), J8.B9 (VBUS), U4.7 (VCC), USB5.1
unnamed: C27.2, U5.2 (CAP)
unnamed: U5.10 (HVLX_L), U5.11 (HVLX_L), U5.12 (HVLX), U5.13 (HVLX)
VCC: C17.2, C24.1, C26.1, R7.1, R18.1, U1.14 (VCC), U2.14 (VCC), U3.4 (VCC), U3.6 (VCC), U5.7 (OUT), U5.8 (OUT), U15.1, U17.5 (VOUT), V2.1

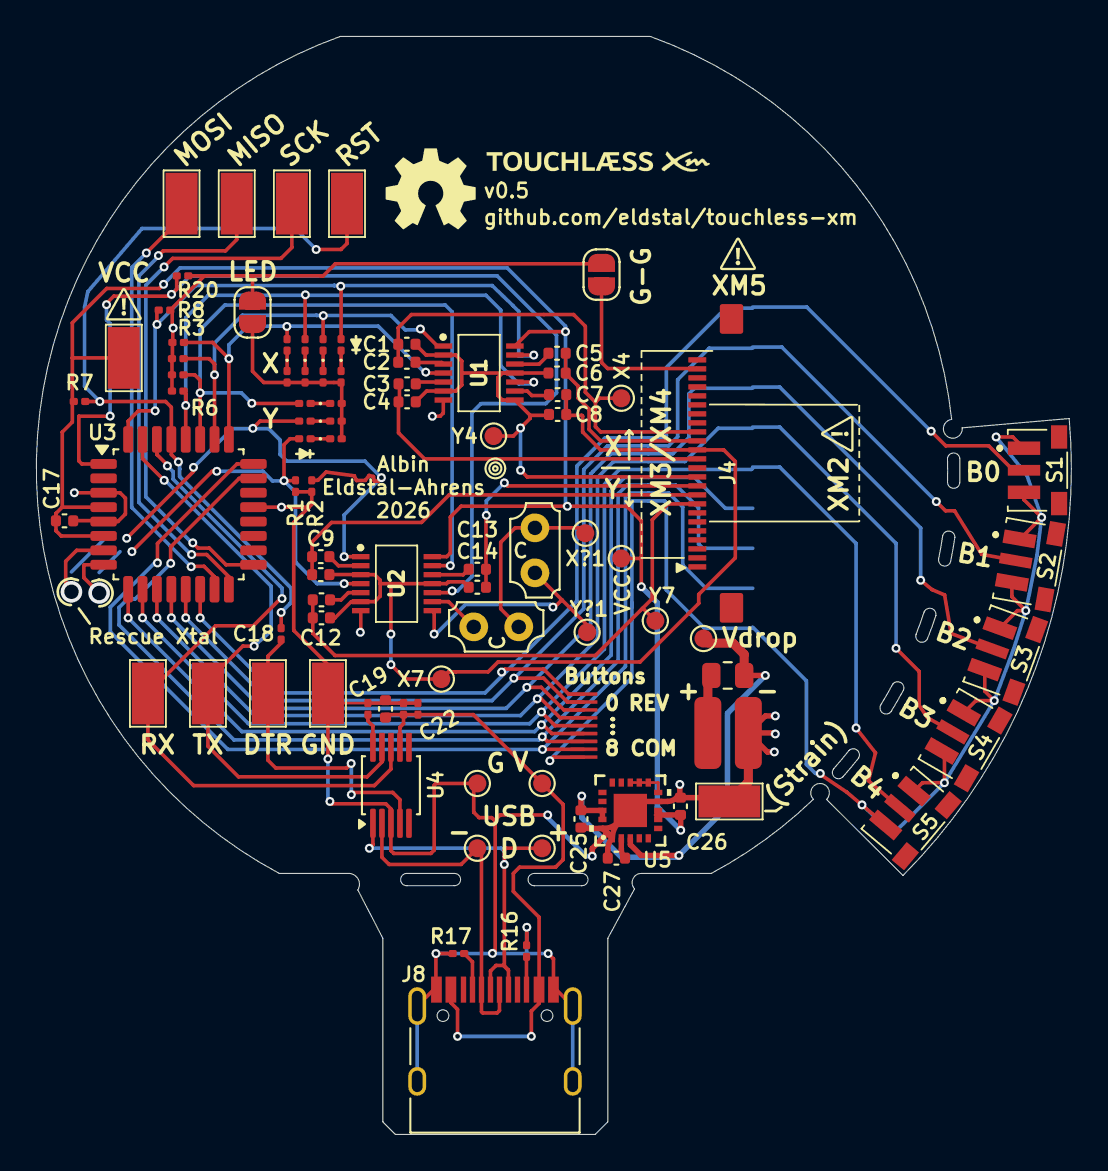
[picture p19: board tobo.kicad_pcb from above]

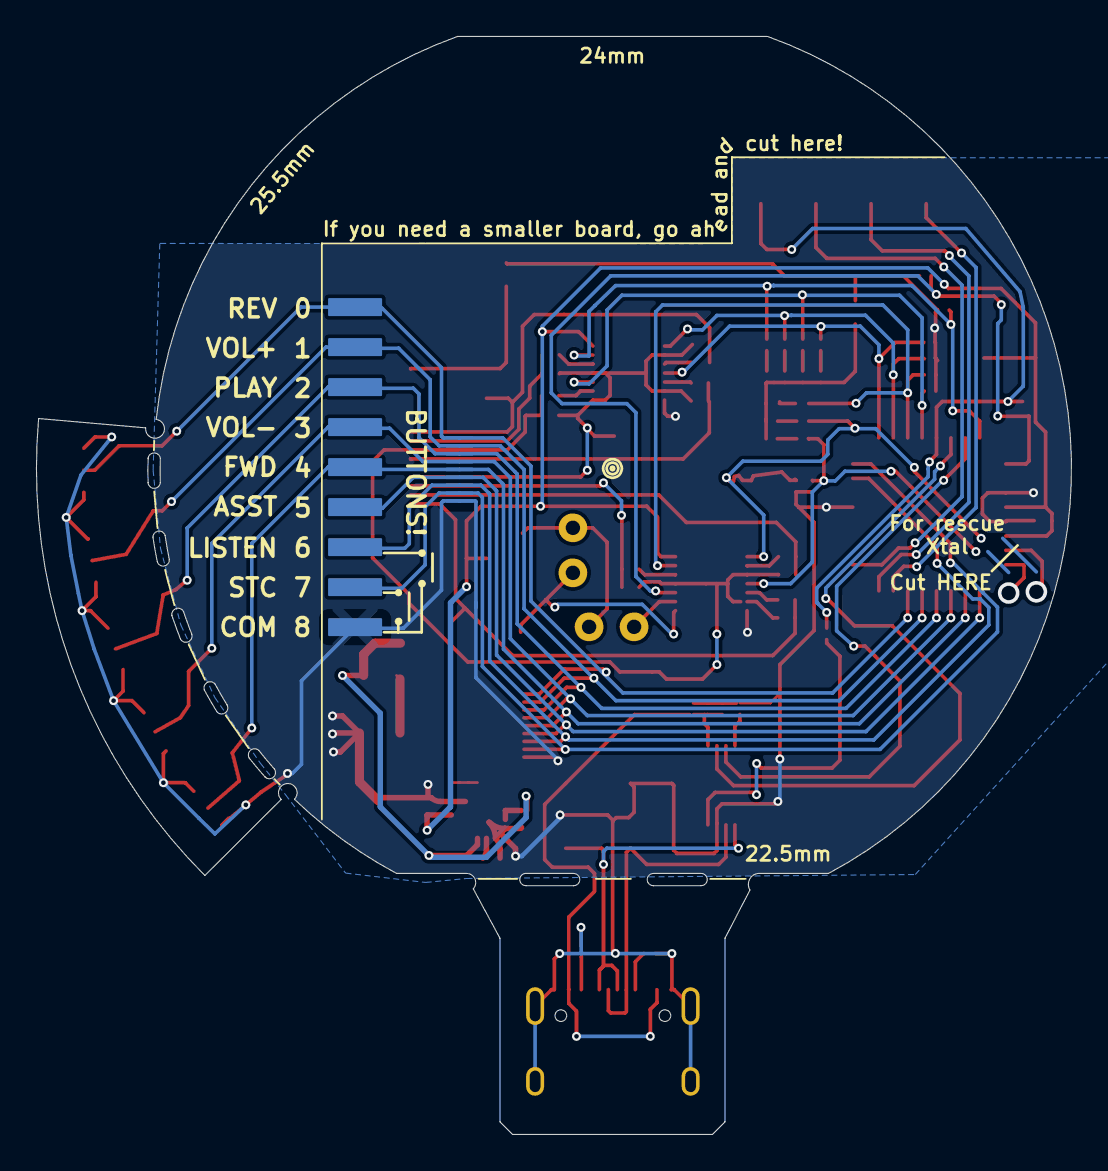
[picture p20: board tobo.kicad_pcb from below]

Board: 2 copper layers, 57.5 x 61.0 mm, 91 parts (2 on the bottom side), 62 nets.

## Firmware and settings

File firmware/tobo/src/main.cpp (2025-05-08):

#include <Arduino.h>

#include <LowPower.h>
#include <PinChangeInterrupt.h>
#include <SimplyAtomic.h>

#include "pinmap.hpp"
#include "gestures.hpp"
#include "debounce.hpp"
#include "buttonmap.hpp"


pin_debounce debounce[N_BTNS] = { };

#define GENERIC_BUTTON_INTERRUPT(idx) \
void btn_int_##idx() { \
    debounce_interrupt(&debounce[idx]); \
}

GENERIC_BUTTON_INTERRUPT(0)
GENERIC_BUTTON_INTERRUPT(1)
GENERIC_BUTTON_INTERRUPT(2)
GENERIC_BUTTON_INTERRUPT(3)
GENERIC_BUTTON_INTERRUPT(4)
GENERIC_BUTTON_INTERRUPT(5)
GENERIC_BUTTON_INTERRUPT(6)
GENERIC_BUTTON_INTERRUPT(7)



void setup_pins() {
    for (unsigned char p=0; p<N_BTNS; ++p) {
        pinMode(BTN_PIN[p], INPUT_PULLUP);
    }

    for (unsigned char p=0; p<N_TOUCH_X; ++p) {
        pinMode(TOUCH_X_PIN[p], OUTPUT);
        digitalWrite(TOUCH_X_PIN[p], TOUCH_INACTIVE);
    }

    for (unsigned char p=0; p<N_TOUCH_Y; ++p) {
        pinMode(TOUCH_Y_PIN[p], OUTPUT);
        digitalWrite(TOUCH_Y_PIN[p], TOUCH_INACTIVE);
    }
}



void setup_interrupts() {
    for (unsigned char p=0; p<N_BTNS; ++p) {
        debounce[p] = { .pin = BTN_PIN[p], .fresh = true };
    }

    attachPCINT(digitalPinToPCINT(BTN_PIN[0]), btn_int_0, CHANGE);
    attachPCINT(digitalPinToPCINT(BTN_PIN[1]), btn_int_1, CHANGE);
    attachPCINT(digitalPinToPCINT(BTN_PIN[2]), btn_int_2, CHANGE);
    attachPCINT(digitalPinToPCINT(BTN_PIN[3]), btn_int_3, CHANGE);
    attachPCINT(digitalPinToPCINT(BTN_PIN[4]), btn_int_4, CHANGE);
    attachPCINT(digitalPinToPCINT(BTN_PIN[5]), btn_int_5, CHANGE);
    attachPCINT(digitalPinToPCINT(BTN_PIN[6]), btn_int_6, CHANGE);
    attachPCINT(digitalPinToPCINT(BTN_PIN[7]), btn_int_7, CHANGE);
}

void setup()
{
    setup_pins();
    setup_interrupts();

}

void loop()
{

    // Sleep until an interrupt
    LowPower.powerDown(SLEEP_FOREVER, ADC_OFF, BOD_OFF);

    bool any_triggered = true;

    // Handle any queued up interrupts
    while (any_triggered) {
        
        // Allow buttons to settle
        delay(DEBOUNCE_MS);
        long now = millis();

        any_triggered = false;

        for (uint8_t p=0; p<N_BTNS; p++) {
            
            bool pin_triggered = false;
            ATOMIC() {
                pin_triggered = debounced_check(&debounce[p], now, BUTTON_ACTIVE);
            }

            if (!pin_triggered) continue;

            any_triggered = true;

            gesture_perform(BTN_ACTION[p], BTN_PIN[p]); 

        }
    }

    //delay(1000);
}

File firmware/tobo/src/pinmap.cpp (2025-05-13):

#include "pinmap.hpp"
#include "headsets.hpp"

const unsigned char BTN_PIN[N_BTNS] = {
    PIN_PB2,
    PIN_PB1,
    PIN_PB0,
    PIN_PD7,
    PIN_PD6,
    PIN_PD5,
    PIN_PC0,
    PIN_PC1
};

const unsigned char BTN_INT[N_BTNS] {
    2,  // PB2
    1,  // PB1
    0,  // PB0
    23, // PD7
    22, // PD6
    21, // PD5
    7,  // PB7
    6   // PB6
};



// Touch points across different X values
const unsigned char TOUCH_X_PIN[N_TOUCH_X] {
    PIN_PC2,  // 1,4   rear
    PIN_PC5,  // 2,4
    PIN_PD2,  // 3,4
    PIN_PC3,  // 4,4   front
};


// Touch points across different Y values
#ifdef IS_XM2
    // The XM2 has its Y pins in a different order
    // in the cable, so we correct for that here
    const unsigned char TOUCH_Y_PIN[N_TOUCH_Y] {
        PIN_PB7, // 2,0,  bottom
        PIN_PB6, // 2,1
        PIN_PC4, // 2,2
        PIN_PC5  // 2,3,  top
    };

#else
    const unsigned char TOUCH_Y_PIN[N_TOUCH_Y] {
        PIN_PC5,  // 2,4,  bottom
        PIN_PC4,  // 2,5
        PIN_PB6,  // 2,6
        PIN_PB7,  // 2,7,  top
    };
#endif

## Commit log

2025-04-29 Design is untested, ready for first prototype run.
    [tobo.kicad_pcb, tobo.kicad_sch, xm4-cap.scad]
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2025-04-29 Another 3d render fix
    [tobo.kicad_pcb]
2025-05-01 Normalize PCB trace thickness and add a VCC attachment
    [tobo.kicad_pcb, tobo.kicad_sch]
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2025-05-04 Fixed DRC violation
    [tobo.kicad_pcb]
2025-05-04 Made the PCB prettier
    [tobo.kicad_pcb, xm4-cap.scad]
2025-05-04 PCB cleanup, RST connector clarification
    [tobo.kicad_pcb, tobo.kicad_sch]
2025-05-04 Separate DTR from RST pin. They are different.
    [tobo.kicad_pcb, tobo.kicad_sch]
2025-05-04 Fix URL in logo
    [tobo.kicad_pcb]
2025-05-04 DRC fix
    [tobo.kicad_pcb]
2025-05-04 Connector name fix
2025-05-06 Cleared edges of USB board
    [tobo.kicad_pcb]
2025-05-06 Fix messed up indentation
    [main.cpp]
2025-05-06 Internal pull-ups for the buttons. May as well.
    [tobo.kicad_pcb, tobo.kicad_sch]
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2025-05-06 Untented all the vias in order to allow a crystal
    We don't actually need one, but if you mess up burning
    the bootloader, you may need to hold a crystal to the contacts
    in order to correct the programming.
    In Kicad 9, we may be able to re-tent all the vias and untent these.
    That would be nice.
    [tobo.kicad_pcb]
2025-05-07 Confirmed pinouts of XM5 and XM5.
    Experimental support for XM2 added.
    [tobo.kicad_pcb, xm4-cap.scad]
2025-05-08 PCB and documentation tweaks
    [tobo.kicad_pcb, tobo.kicad_sch]
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2025-05-08 Swapped some GPIO to avoid PCINT problems
    This lead to a tasty basket weave of traces under the MCU, but that's
    fine I guess.
    The only reason this change was "necessary" is because regular arduino
    doesn't expose gpio on the crystal pins. Therefore the PCINT libraries
    don't seem to support enabling the pin change interrupt on those pins.
    It was neat to have them as buttons, from a routing perspective, but
    this should -work- which seems more important.
    [tobo.kicad_pcb, tobo.kicad_sch]
2025-05-10 Maybe we can use TPU filament raw for a gasket?
    [xm4-cap.scad]
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2025-05-10 Broke the buttons out of the SCAD exports
    [xm4-cap.scad]
2025-05-13 Fixed order of Y LEDs
    [tobo.kicad_pcb]
2025-05-13 Silkscreen guide for hand soldering to a different headset
    [tobo.kicad_pcb]
2025-05-14 Remove the endcaps on the button box.
    I'd like to include the buttons in the case design better, but not sure
    just how.
    I guess the only -important- shapes are the cutouts for PCB and buttons,
    the casing itself can be any wonky shape...
    [xm4-cap.scad]
2025-05-15 Fitting of XM4 cap. Screw holes etc are good!
    [xm4-cap.scad]
2025-05-15 More fit tweaking. Untested.
    [xm4-cap.scad]
2025-05-16 Separate the mic grill from the rest of the print
    [xm4-cap.scad]
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2025-05-17 Moved autogenerated PCB files to dist/
    [tobo.kicad_sch, xm4-cap.scad]
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2025-05-18 Bumped PCB version to v1.0a
    Changes will still be made, I just want it to be labeled
    differently from the ones I've ordered for fabrication
    [tobo.kicad_pcb]
2025-05-19 Screw posts properly aligned for XM4
    [xm4-cap.scad]
2025-05-19 Attempts to clear up some printing problems.
    There's still a section of weak wall just above the button box, for some
    reason. Prusa slicer makes it a single wall rather than the solid
    double-layer it uses around the rest of the perimeter.
    [xm4-cap.scad]
2025-05-19 Made the board significantly cheaper to manufacture.
    Now there's only one connector (these things are like $5 each :D)
    and some of the caps were super expensive too.
    Also fixed some incomplete part numbers, so the BOM should be
    better for the next attempt at fabrication.
    [tobo.kicad_pcb, tobo.kicad_sch]
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2025-05-19 Fixed an ugly wall breach in the cap model
    [xm4-cap.scad]
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2025-05-20 Oops, the connector was on the "safe to cut" board.
    It's not a functional issue, just don't go nuts with the saw!
    [tobo.kicad_pcb]
2025-05-20 Explain yourself in the schematic
    [tobo.kicad_sch]
2025-05-20 Fixed printing inconsistency in the PCB mounting surface
    [xm4-cap.scad]
2025-05-20 "Release" v0.3a of the PCB, ready for manufacture.
    BOM cost is about $17 per board.
    [tobo-B_Cu.gbl, tobo-B_Mask.gbs, tobo-B_Paste.gbp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]
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2025-05-20 Automatic CAD preview generation
    [xm4-cap.scad]
2025-05-20 A dummy PCB to 3d-print for fit testing
    [xm4-cap.scad]
2025-05-21 Clearance trimming for PCB mount
    [xm4-cap.scad]
2025-05-21 Embiggened buttons, tried to make mic hole print cleanly
    [xm4-cap.scad]
2025-05-21 Adaptations for printing (cut down overhangs, etc.
    In particular, the buttons are now more suited to printing without
    support, face up. Sad about the surface, which became really nice when
    printed face down.
    [xm4-cap.scad]
2025-05-21 Print-friendly buttons. We'll see.
    [xm4-cap.scad]
2025-05-21 Better USB board mounting.
    Also eliminated some more overhangs. We're getting there.
    [xm4-cap.scad]
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2025-05-22 Cleaned up parameters in SCAD
    [xm4-cap.scad]
2025-05-23 Cleaned up configs a bit. Added a cool button cutaway.
    [xm4-cap.scad]
2025-05-23 Fixed parts rendering
    [xm4-cap.scad]
2025-05-23 Built-in print supports for the two tricky openings
    [xm4-cap.scad]
2025-05-23 Another attempt at a microphone grill
    [xm4-cap.scad]
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2025-05-29 Added clarification to silkscreen
    Also bumped PCB version to 0.4
    [tobo.kicad_pcb]
2025-05-30 Adjusted PCB clips and print supports
    [xm4-cap.scad]
2025-06-02 Clean up release directory
    [tobo-B_Cu.gbl, tobo-B_Mask.gbs, tobo-B_Paste.gbp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]
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2025-06-18 Solution to the PCB error in v0.3a
    If you've got a v0.4 board, no need to futz around with RX/TX.
    [tobo.kicad_pcb, tobo.kicad_sch]
2025-12-25 PCB: Bump to Kicad 9 and preparation for step-up transformer
    [tobo.kicad_pcb, tobo.kicad_sch]
2025-12-25 First stab at a step-up converter on the tobo
    [tobo.kicad_pcb, tobo.kicad_sch, tobo.scad]
2025-12-28 Half-way to a better transformer
    [tobo.kicad_pcb, tobo.kicad_sch]
2025-12-28 A mostly one-chip up- and down- converter.
    This should work down to 0.5V, which is just a little bit over the low
    battery warning of the headset.
    [tobo.kicad_pcb, tobo.kicad_sch, tobo.scad]
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2025-12-28 Some kind of bug in screenshot generation
    Nothing should have changed in the SCAD files, but I have no idea why
    openscad regenerated them or why git diffs them as changed
    [xm4-cap.scad]
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2025-12-29 Reworked PCB to use TC7MBL3125CFK bus switches
    The old design didn't work, and I suspect it's due to the excessive
    capacitance of the analog mux. This chip (~roughly) has been tested
    against XM4s on the bench and works great with 1.5pF capacitors.
    [tobo.kicad_pcb, tobo.kicad_sch]
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2025-12-29 Inverted mux control signals for v0.5 board
2026-01-03 Unused controller now has through-hole caps for experimentation
    [tobo.kicad_pcb, tobo.kicad_sch]
2026-01-04 PCB tweaks and prettification
    [tobo.kicad_pcb, tobo.kicad_sch]
2026-01-04 PCB tweaks and screenshot prettier
    [HRO TYPE-C-31-M-12.step, MAXM20343AMP+.stp, TC7MBL3125CFK_EL_.stp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]
2026-01-07 Added missing pull-up for previously unused control channel
    [tobo.kicad_pcb, tobo.kicad_sch]
2026-01-09 OK, last little change before next prototype goes off for manufacturing
    [tobo.kicad_pcb]
2026-01-09 Hooked the voltage converter up the right way around. Good catch!
    [tobo.kicad_pcb, tobo.kicad_sch]
2026-01-13 Finalized files for PCB v0.5, which have been accepted by the fab house
    [tobo-bom.csv, tobo.kicad_pcb, tobo.scad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]
2026-02-10 Reduced brown-out voltage (new board wasn't working at 3.3!)
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2026-02-14 Preparations for a case with a logo medallion on it
    [xm4-cap.scad]
2026-02-14 An attempt to better differentiate the buttons
    [xm4-cap.scad]
2026-02-14 A big fat logo on the outside, maybe?
    [xm4-cap.scad]
2026-02-14 Less gaudy logo rendering
    [xm4-cap.scad]
2026-02-15 New approach to the microphone grill
    [xm4-cap.scad]
2026-02-15 Flattened xm4-parts model, so everyting prints on one surface
    [xm4-cap.scad]
2026-02-18 Shortened buttons slightly
    [xm4-cap.scad]
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2026-02-18 Thicker cap body, hopefully reduces distortion of outside
    [xm4-cap.scad]
2026-02-20 Printability fixes and tweaks to PCB mount
    [xm4-cap.scad]
2026-02-23 Preparations for a slightly pulled-in button layout
    In the previous design, laying the headset on a table would press the
    top button.
    This redesign pulls it in 2mm so that the headset rests on the frame
    instead. It requires some more tweaking of the button box, though.
    [xm4-cap.scad]
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2026-02-26 Move button box out of the way of the headset's table stance
    We'll see if it interferes with the fork. The USB flavor looks pretty
    bad now, since this required rotating the PCB but that's fine.
    [xm4-cap.scad]
